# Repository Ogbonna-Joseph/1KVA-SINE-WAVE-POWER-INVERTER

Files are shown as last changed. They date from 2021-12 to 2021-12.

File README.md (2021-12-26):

# 1KVA-SINE-WAVE-POWER-INVERTER
This is a design of a sine wave power inverter, which can be used in your homes and offices.

IN the design the Inverter converts 12v/24v to 220volts.

# SECTIONS OF THE DESIGN
- Power Section : This consist of the battery portion, here we used 12v acid battery to power it on.
- Oscillator : This is the part that the frequency and signals are  being generation to feed to the MOSFET.
- Booster : This involves the mosfet switching the signal state and giving to the transmorfer.
- Output : Here the transformer gives an output of 220volts..

# SCHEMATICS OF PCB BOARD
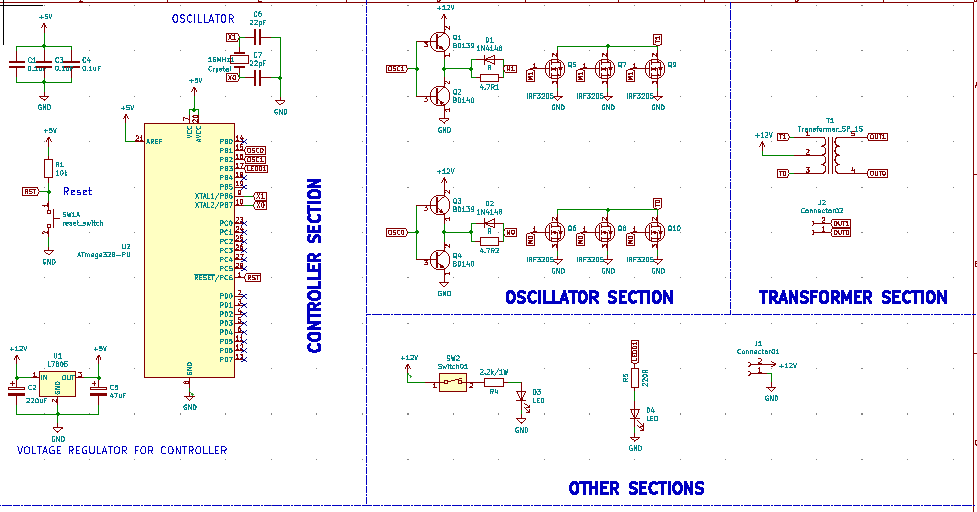
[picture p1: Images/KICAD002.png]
schematics


#  PCB ROUTE SECTION
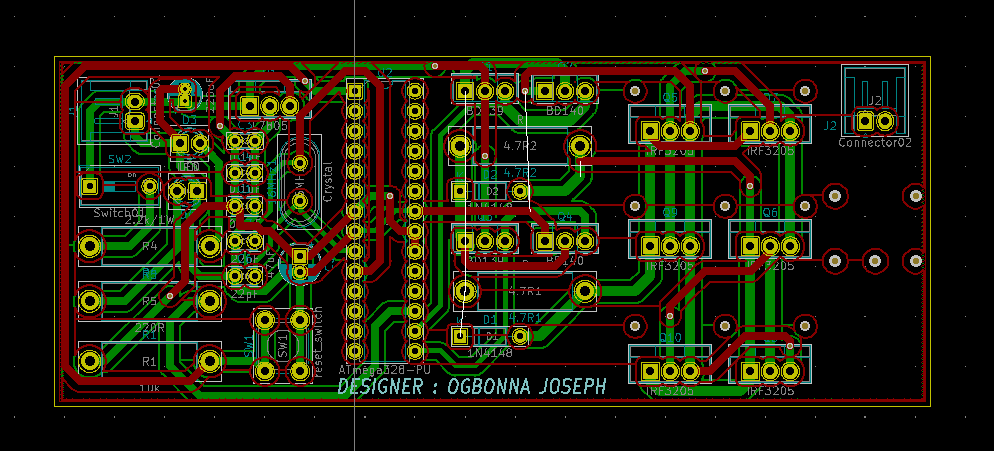
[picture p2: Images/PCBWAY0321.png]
LAYOUT


# PCB BOARD
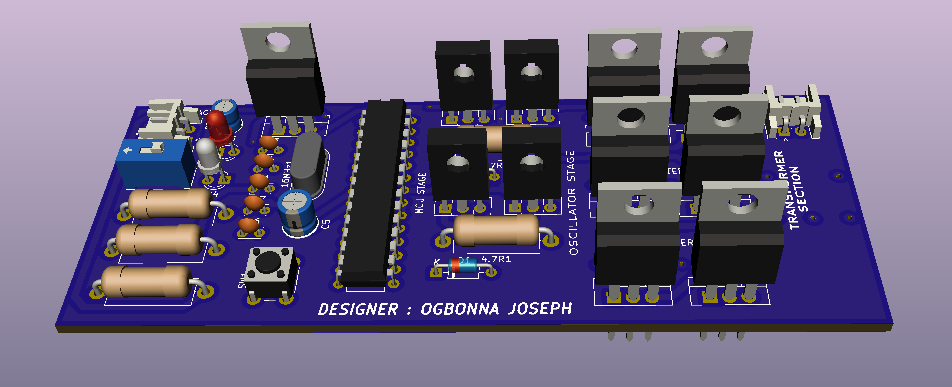
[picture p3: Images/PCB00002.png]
PCB


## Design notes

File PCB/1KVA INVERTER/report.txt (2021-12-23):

Annotated IRF3205 as Q7
Annotated C as C5
Annotated C as C6
Annotated C as C7
Annotated 1N4148 as D1
Annotated 1N4148 as D2
Annotated LED as D3
Annotated LED as D4
Annotated Conn_01x02_Female as J1
Annotated Conn_01x02_Female as J2
Annotated BD139 as Q1
Annotated BD140 as Q2
Annotated BD139 as Q3
Annotated BD140 as Q4
Annotated IRF3205 as Q5
Annotated IRF3205 as Q6
Annotated C as C4
Annotated IRF3205 as Q8
Annotated IRF3205 as Q9
Annotated IRF3205 as Q10
Annotated R as R1
Annotated R as R2
Annotated R as R3
Annotated R as R4
Annotated R as R5
Annotated SW_Push_Dual_x2 (unit A) as SW1A
Annotated SW_DIP_x01 as SW2
Annotated Transformer_SP_1S as T1
Annotated L7805 as U1
Annotated ATmega328-PU as U2
Annotated Crystal as Y1
Annotated GND as #PWR016
Annotated +5V as #PWR02
Annotated GND as #PWR03
Annotated +5V as #PWR04
Annotated GND as #PWR05
Annotated GND as #PWR06
Annotated +5V as #PWR07
Annotated +5V as #PWR08
Annotated GND as #PWR09
Annotated +5V as #PWR010
Annotated GND as #PWR011
Annotated +12V as #PWR012
Annotated +12V as #PWR013
Annotated GND as #PWR014
Annotated +12V as #PWR015
Annotated +12V as #PWR01
Annotated GND as #PWR017
Annotated GND as #PWR018
Annotated GND as #PWR019
Annotated GND as #PWR020
Annotated GND as #PWR021
Annotated GND as #PWR022
Annotated GND as #PWR023
Annotated GND as #PWR024
Annotated +12V as #PWR025
Annotated +12V as #PWR026
Annotated GND as #PWR027
Annotated C as C1
Annotated C as C2
Annotated C as C3

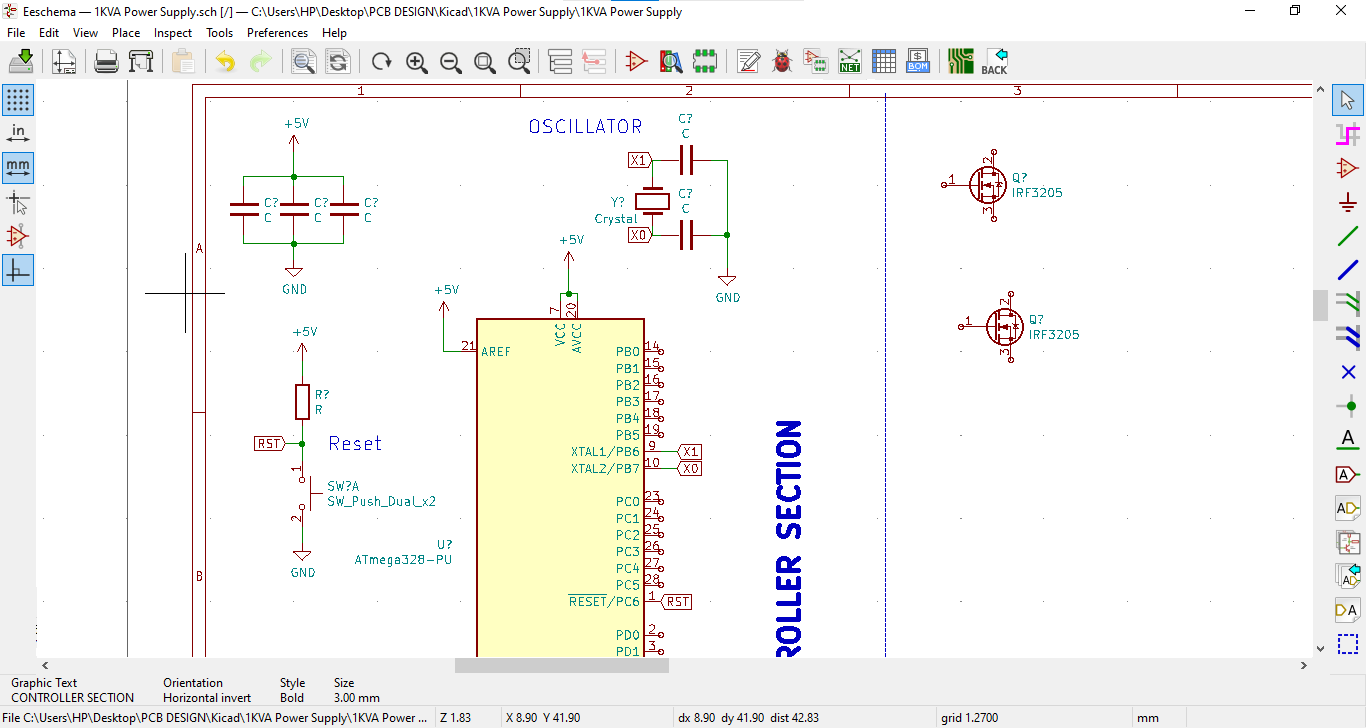
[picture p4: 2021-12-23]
Images/Schematics001.png

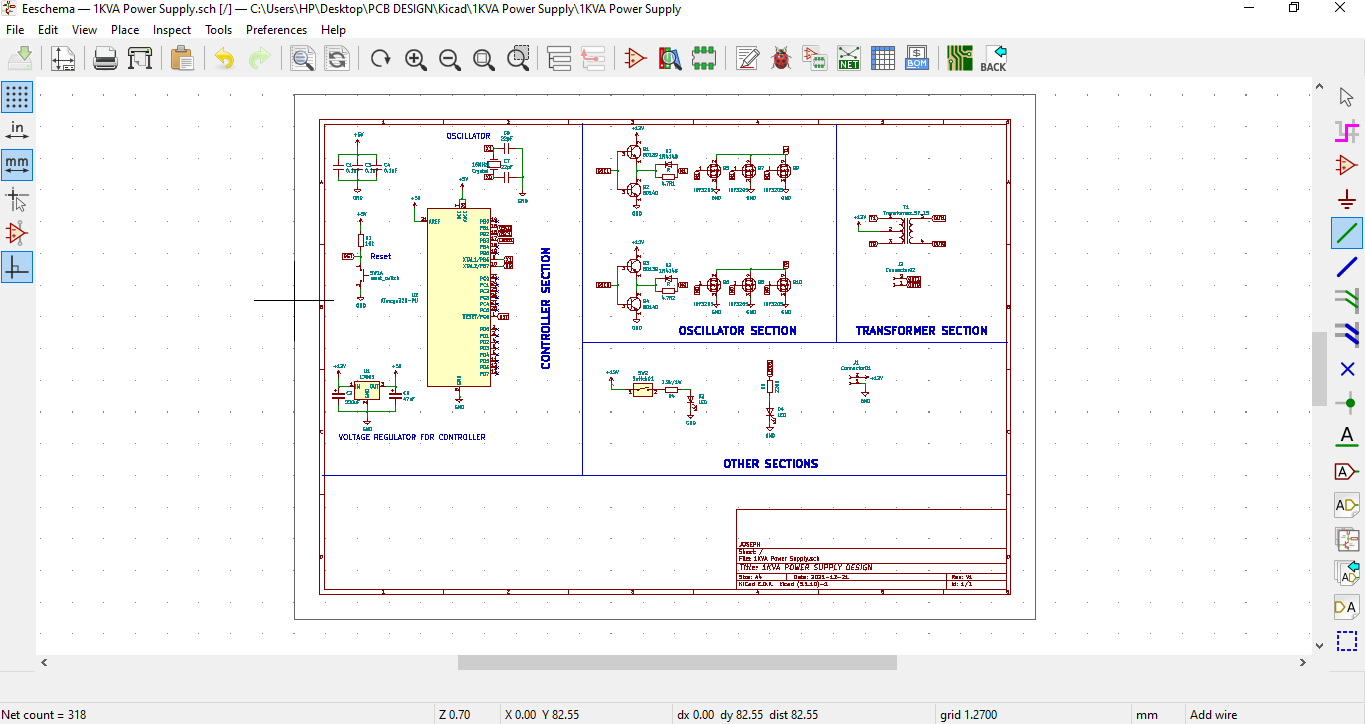
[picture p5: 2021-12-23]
Images/kicad03.png

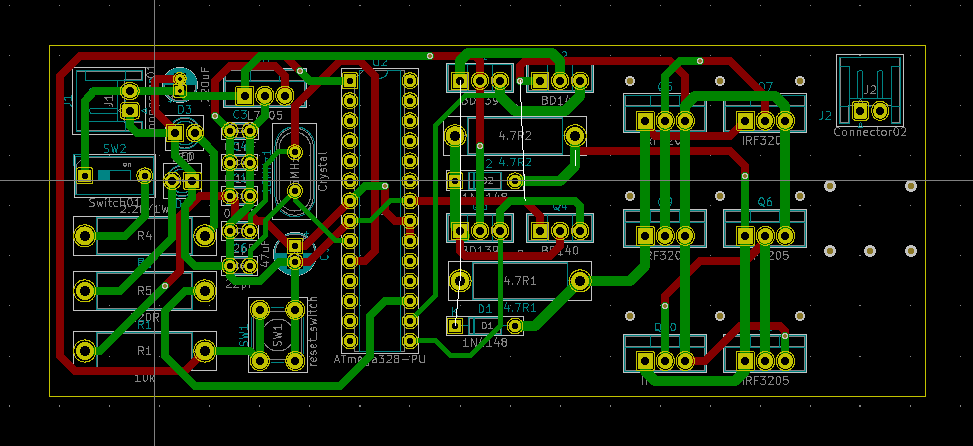
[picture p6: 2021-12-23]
Images/pcbway004.png

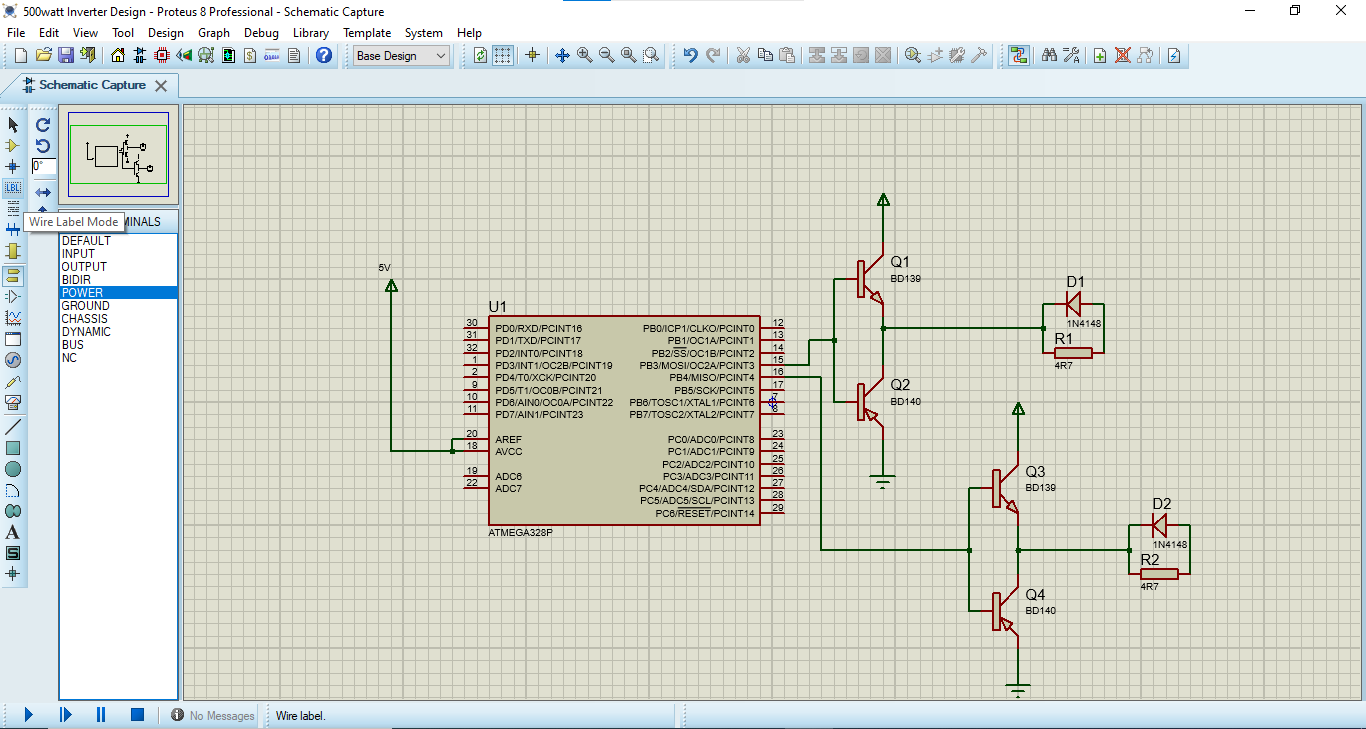
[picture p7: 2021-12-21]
Images/Inverter01.png

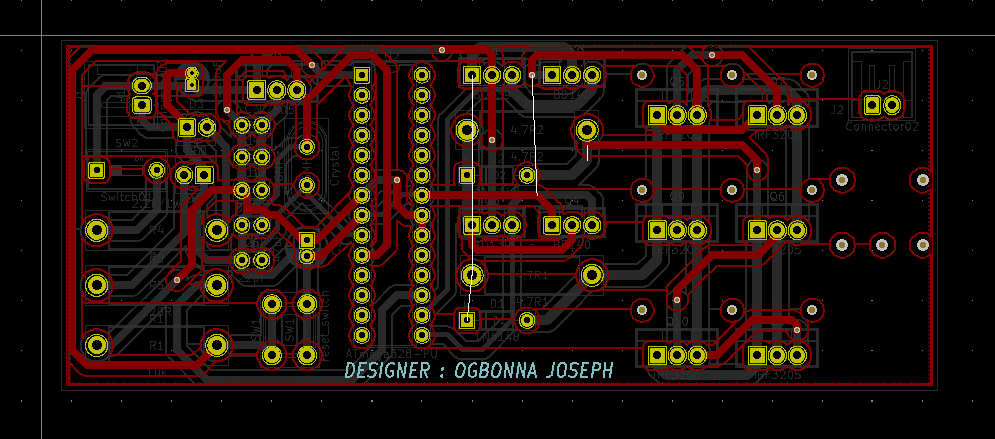
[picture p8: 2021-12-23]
Images/PCB0111.png

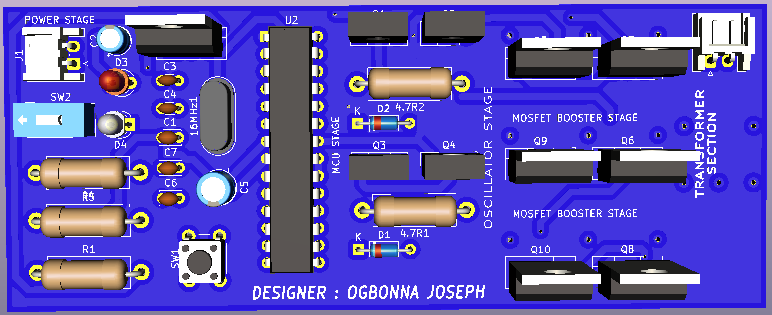
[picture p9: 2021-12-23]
Images/PCB012.png

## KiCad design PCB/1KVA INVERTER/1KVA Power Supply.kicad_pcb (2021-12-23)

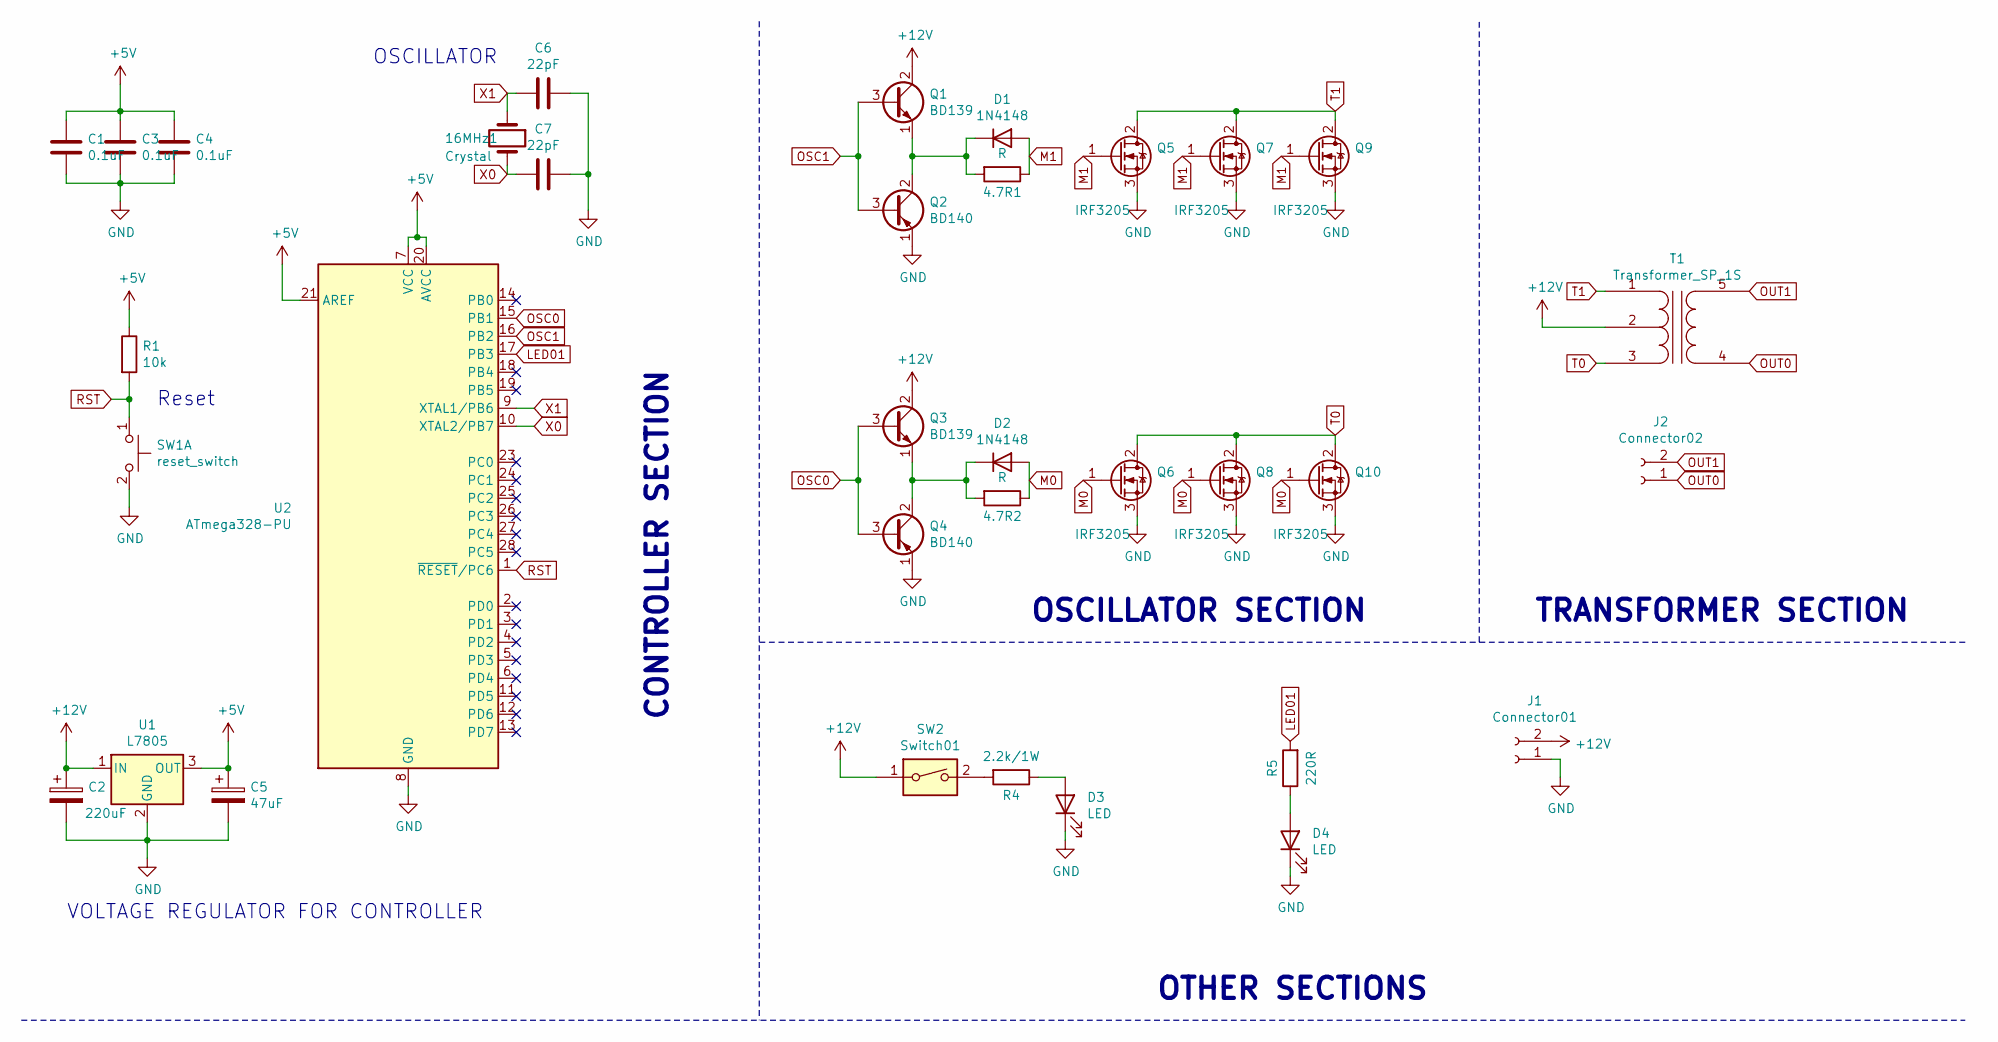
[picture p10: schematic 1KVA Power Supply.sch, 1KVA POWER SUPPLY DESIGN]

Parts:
4.7R1, 4.7R2: R; R_Axial_DIN0414_L11.9mm_D4.5mm_P15.24mm_Horizontal
16MHz1: Crystal; Crystal_HC49-4H_Vertical
C1: 0.1uF; C_Disc_D3.0mm_W2.0mm_P2.50mm
C2: 220uF; CP_Radial_D4.0mm_P1.50mm
C3, C4: 0.1uF; C_Disc_D3.0mm_W1.6mm_P2.50mm
C5: 47uF; CP_Radial_D5.0mm_P2.00mm
C6, C7: 22pF; C_Disc_D3.0mm_W2.0mm_P2.50mm
D1, D2: 1N4148; D_DO-35_SOD27_P7.62mm_Horizontal
D3: LED; LED_D3.0mm
D4: LED; LED_D3.0mm_Clear
J1: Connector01; JST_EH_S2B-EH_1x02_P2.50mm_Horizontal
J2: Connector02; JST_EH_S2B-EH_1x02_P2.50mm_Horizontal
Q1, Q3: BD139; TO-126-3_Vertical
Q2, Q4: BD140; TO-126-3_Vertical
Q5, Q6, Q7, Q8, Q9, Q10: IRF3205; TO-220-3_Vertical
R1: 10k; R_Axial_DIN0414_L11.9mm_D4.5mm_P15.24mm_Horizontal
R4: 2.2k/1W; R_Axial_DIN0414_L11.9mm_D4.5mm_P15.24mm_Horizontal
R5: 220R; R_Axial_DIN0414_L11.9mm_D4.5mm_P15.24mm_Horizontal
SW1: reset_switch; SW_PUSH_6mm
SW2: Switch01; SW_DIP_SPSTx01_Slide_9.78x4.72mm_W7.62mm_P2.54mm
T1: Transformer_SP_1S; Transformer_MACOM_SM-22
U1: L7805; TO-220-3_Vertical
U2: ATmega328-PU; DIP-28_W7.62mm

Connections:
+5V: C1.1, C3.1, C4.1, C5.1, R1.1, U1.3 (OUT), U2.7 (VCC), U2.20 (AVCC), U2.21 (AREF)
+12V: C2.1, J1.2, Q1.2 (C), Q3.2 (C), SW2.1, T1.2 (PM), U1.1 (IN)
GND: C1.2, C2.2, C3.2, C4.2, C5.2, C6.1, C7.1, D3.1 (K), D4.1 (K), J1.1, Q2.1 (E), Q4.1 (E), Q5.3 (S), Q6.3 (S), Q7.3 (S), Q8.3 (S), Q9.3 (S), Q10.3 (S), SW1.2 (D), U1.2 (GND), U2.8 (GND), U2.22 (GND)
LED01: R5.2, U2.17 (PB3)
M0: 4.7R2.1, D2.2 (A), Q6.1 (G), Q8.1 (G), Q10.1 (G)
M1: 4.7R1.1, D1.2 (A), Q5.1 (G), Q7.1 (G), Q9.1 (G)
unnamed: 4.7R1.2, D1.1 (K), Q1.1 (E), Q2.2 (C)
unnamed: 4.7R2.2, D2.1 (K), Q3.1 (E), Q4.2 (C)
unnamed: D3.2 (A), R4.1
unnamed: D4.2 (A), R5.1
unnamed: R4.2, SW2.2
OSC0: Q3.3 (B), Q4.3 (B), U2.15 (PB1)
OSC1: Q1.3 (B), Q2.3 (B), U2.16 (PB2)
OUT0: J2.1, T1.4 (S1)
OUT1: J2.2, T1.5 (S2)
RST: R1.2, SW1.1 (C), U2.1 (~RESET~/PC6)
T0: Q6.2 (D), Q8.2 (D), Q10.2 (D), T1.3 (PR2)
T1: Q5.2 (D), Q7.2 (D), Q9.2 (D), T1.1 (PR1)
X0: 16MHz1.2, C7.2, U2.10 (XTAL2/PB7)
X1: 16MHz1.1, C6.2, U2.9 (XTAL1/PB6)

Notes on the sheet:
Reset
OSCILLATOR
VOLTAGE REGULATOR FOR CONTROLLER
CONTROLLER SECTION
OSCILLATOR SECTION
TRANSFORMER SECTION
OTHER SECTIONS

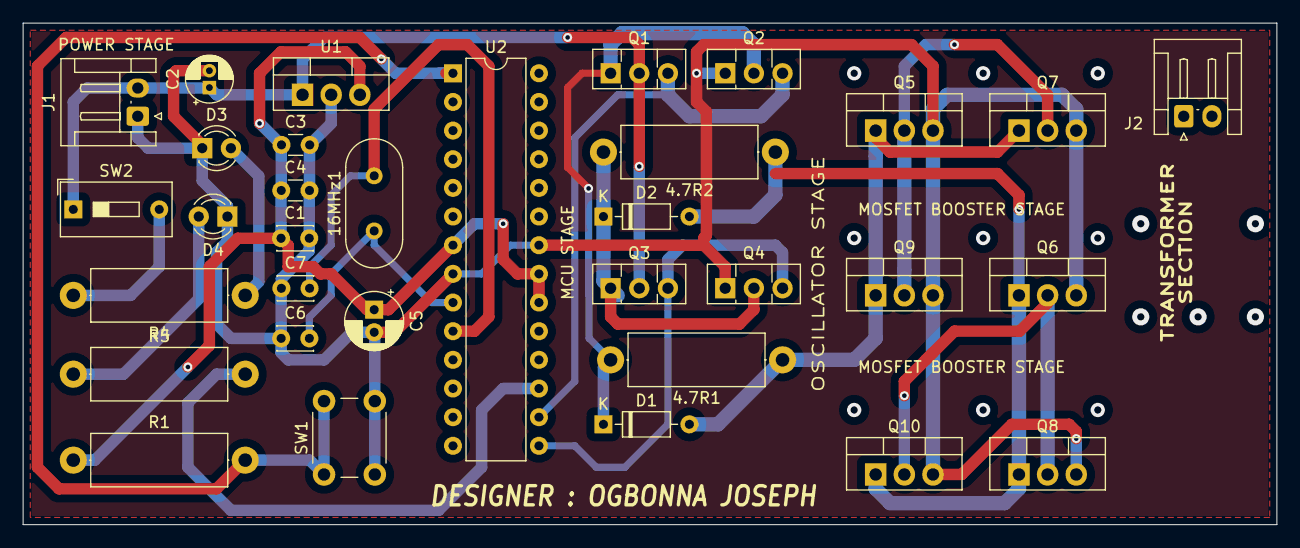
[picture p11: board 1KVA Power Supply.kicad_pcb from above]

Board: 2 copper layers, 111.1 x 44.5 mm, 33 parts (0 on the bottom side), 18 nets.

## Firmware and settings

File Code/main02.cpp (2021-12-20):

/*
Author : OGBONNA JOSEPH
DATE : 20-12-2021
*/
const int sPWMArray[] = {500,500,750,500,1250,500,2000,500,1250,500,750,500,500}; // This is the array with the SPWM values change them at will
const int sPWMArrayValues = 13; // You need this since C doesn’t give you the length of an Array
// The pins
const int sPWMpin1 = 10;
const int sPWMpin2 = 9;
// The pin switches
bool sPWMpin1Status = true;
bool sPWMpin2Status = true;
void setup()
{
pinMode(sPWMpin1, OUTPUT);
pinMode(sPWMpin2, OUTPUT);
}
void loop()
{
// Loop for pin 1
for(int i(0); i != sPWMArrayValues; i++)
{
if(sPWMpin1Status)
{
digitalWrite(sPWMpin1, HIGH);
delayMicroseconds(sPWMArray[i]);
sPWMpin1Status = false;
}
else
{
digitalWrite(sPWMpin1, LOW);
delayMicroseconds(sPWMArray[i]);
sPWMpin1Status = true;
}
}
// Loop for pin 2
for(int i(0); i != sPWMArrayValues; i++)
{
if(sPWMpin2Status)
{
digitalWrite(sPWMpin2, HIGH);
delayMicroseconds(sPWMArray[i]);
sPWMpin2Status = false;
}
else
{
digitalWrite(sPWMpin2, LOW);
delayMicroseconds(sPWMArray[i]);
sPWMpin2Status = true;
}
}
}

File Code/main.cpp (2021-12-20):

/*
* sPWMv2.c
*
* Created: 20/12/2021
*  Author: Ogbonna Joseph
SPWM on the atMega328 , might be compatible with other atmel chips.
Compare outputs A and B output to PORTB pins 1 and 2 which are pins 9 and 10 respectively on the Chip.
Also useful to know the led on the Chip is pin 5 on PORTB.
*/
#include <avr/io.h>
#include <avr/interrupt.h>
// Look up tables with 200 entries each, normalised to have max value of 1600 which is the period of the PWM loaded into register ICR1.
int lookUp1[] = {50 ,100 ,151 ,201 ,250 ,300 ,349 ,398 ,446 ,494 ,542 ,589 ,635 ,681 ,726 ,771 ,814 ,857 ,899 ,940 ,981 ,1020 ,1058 ,1095 ,1131 ,1166 ,1200 ,1233 ,1264 ,1294 ,1323 ,1351 ,1377 ,1402 ,1426 ,1448 ,1468 ,1488 ,1505 ,1522 ,1536 ,1550 ,1561 ,1572 ,1580 ,1587 ,1593 ,1597 ,1599 ,1600 ,1599 ,1597 ,1593 ,1587 ,1580 ,1572 ,1561 ,1550 ,1536 ,1522 ,1505 ,1488 ,1468 ,1448 ,1426 ,1402 ,1377 ,1351 ,1323 ,1294 ,1264 ,1233 ,1200 ,1166 ,1131 ,1095 ,1058 ,1020 ,981 ,940 ,899 ,857 ,814 ,771 ,726 ,681 ,635 ,589 ,542 ,494 ,446 ,398 ,349 ,300 ,250 ,201 ,151 ,100 ,50 ,0 ,0 ,0 ,0 ,0 ,0 ,0 ,0 ,0 ,0 ,0 ,0 ,0 ,0 ,0 ,0 ,0 ,0 ,0 ,0 ,0 ,0 ,0 ,0 ,0 ,0 ,0 ,0 ,0 ,0 ,0 ,0 ,0 ,0 ,0 ,0 ,0 ,0 ,0 ,0 ,0 ,0 ,0 ,0 ,0 ,0 ,0 ,0 ,0 ,0 ,0 ,0 ,0 ,0 ,0 ,0 ,0 ,0 ,0 ,0 ,0 ,0 ,0 ,0 ,0 ,0 ,0 ,0 ,0 ,0 ,0 ,0 ,0 ,0 ,0 ,0 ,0 ,0 ,0 ,0 ,0 ,0 ,0 ,0 ,0 ,0 ,0 ,0 ,0 ,0 ,0 ,0 ,0 ,0 ,0 ,0 ,0 ,0 ,0 ,0 ,0};
int lookUp2[] = {0 ,0 ,0 ,0 ,0 ,0 ,0 ,0 ,0 ,0 ,0 ,0 ,0 ,0 ,0 ,0 ,0 ,0 ,0 ,0 ,0 ,0 ,0 ,0 ,0 ,0 ,0 ,0 ,0 ,0 ,0 ,0 ,0 ,0 ,0 ,0 ,0 ,0 ,0 ,0 ,0 ,0 ,0 ,0 ,0 ,0 ,0 ,0 ,0 ,0 ,0 ,0 ,0 ,0 ,0 ,0 ,0 ,0 ,0 ,0 ,0 ,0 ,0 ,0 ,0 ,0 ,0 ,0 ,0 ,0 ,0 ,0 ,0 ,0 ,0 ,0 ,0 ,0 ,0 ,0 ,0 ,0 ,0 ,0 ,0 ,0 ,0 ,0 ,0 ,0 ,0 ,0 ,0 ,0 ,0 ,0 ,0 ,0 ,0 ,0 ,50 ,100 ,151 ,201 ,250 ,300 ,349 ,398 ,446 ,494 ,542 ,589 ,635 ,681 ,726 ,771 ,814 ,857 ,899 ,940 ,981 ,1020 ,1058 ,1095 ,1131 ,1166 ,1200 ,1233 ,1264 ,1294 ,1323 ,1351 ,1377 ,1402 ,1426 ,1448 ,1468 ,1488 ,1505 ,1522 ,1536 ,1550 ,1561 ,1572 ,1580 ,1587 ,1593 ,1597 ,1599 ,1600 ,1599 ,1597 ,1593 ,1587 ,1580 ,1572 ,1561 ,1550 ,1536 ,1522 ,1505 ,1488 ,1468 ,1448 ,1426 ,1402 ,1377 ,1351 ,1323 ,1294 ,1264 ,1233 ,1200 ,1166 ,1131 ,1095 ,1058 ,1020 ,981 ,940 ,899 ,857 ,814 ,771 ,726 ,681 ,635 ,589 ,542 ,494 ,446 ,398 ,349 ,300 ,250 ,201 ,151 ,100 ,50 ,0};
void setup(){
    // Register initialization, see datasheet for more detail.
    TCCR1A = 0b10100010;
       /*10 clear on match, set at BOTTOM for compA.
         10 clear on match, set at BOTTOM for compB.
         00
         10 WGM1 1:0 for waveform 15.
       */
    TCCR1B = 0b00011001;
       /*000
         11 WGM1 3:2 for waveform 15.
         001 no prescale on the counter.
       */
    TIMSK1 = 0b00000001;
       /*0000000
         1 TOV1 Flag interrupt enable.
       */
    ICR1   = 1600;     // Period for 16MHz crystal, for a switching frequency of 100KHz for 200 subdivisions per 50Hz sine wave cycle.
    sei();             // Enable global interrupts.
    DDRB = 0b00000110; // Set PB1 and PB2 as outputs.
    pinMode(13,OUTPUT);
}
void loop(){; /*Do nothing . . . . forever!*/}
ISR(TIMER1_OVF_vect){
    static int num;
    static char trig;
    // change duty-cycle every period.
    OCR1A = lookUp1[num];
    OCR1B = lookUp2[num];
    if(++num >= 200){ // Pre-increment num then check it's below 200.
       num = 0;       // Reset num.
       trig = trig^0b00000001;
       digitalWrite(13,trig);
     }
}

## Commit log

2021-12-20 Create Kicad
2021-12-23 PCB DESIGN FILES
    [1KVA Power Supply.kicad_pcb, 1KVA Power Supply.sch]
